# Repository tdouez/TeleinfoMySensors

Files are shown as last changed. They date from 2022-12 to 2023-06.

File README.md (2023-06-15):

# TeleinfoMySensors v2.1.0

Interface Téléinfo pour compteur Linky avec MySensors - version compatible mode standard et historique

Projet utilisant un Arduino Pro micro et un module NRF24L01

- Hardware disponible sur https://www.openhardware.io/view/744/MySensors-Linky
- Boîtier disponible sur https://www.thingiverse.com/thing:3985437
- Description disponible sur http://fumeebleue.fr

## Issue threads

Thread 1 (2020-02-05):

Contact boxenergie

sunsharebox, 2020-02-05:
Bonjour,
Je développe la boxenergie pour les particuliers qui veulent faire des économies d'énergie ou ont du solaire en autoconsommation.(http://demo.sunshare.fr)
Ce projet est opensource sur base raspberry avec liaison filaire sur linky et compteur à impulsion.
Votre solution est intéressante. Je vais la tester sur mon linky.
Je suis en mode standard (115200 BAUD), est ce possible ?
Pourrais on ajouter le traitement des impulsions à votre module radio ?
Il y a plusieurs projets en cours dans la communauté (electronique et informatique) avec l'école polytech de Nantes. Vous pouvez rejoindre notre communauté.
Crdlt.

tdouez, 2020-02-06:
Bonjour,
  Le module est compatible avec le mode  historique en 1200bauds et le nouveau mode en 9600bauds mais la partie logicielle qui a été écrite pour le 1200bauds. Pour le mode impulsionnel il faut aller sur le site de MySensors il y a la description du capteur pour ce mode.

Tristan

Le 6 févr. 2020 à 00:25, sunshare <notifications@github.com> a écrit :

Bonjour,
Je développe la boxenergie pour les particuliers qui veulent faire des économies d'énergie ou ont du solaire en autoconsommation.(http://demo.sunshare.fr)
Ce projet est opensource sur base raspberry avec liaison filaire sur linky et compteur à impulsion.
Votre solution est intéressante. Je vais la tester sur mon linky.
Je suis en mode standard (115200 BAUD), est ce possible ?
Pourrais on ajouter le traitement des impulsions à votre module radio ?
Il y a plusieurs projets en cours dans la communauté (electronique et informatique) avec l'école polytech de Nantes. Vous pouvez rejoindre notre communauté.
Crdlt.

—
You are receiving this because you are subscribed to this thread.
Reply to this email directly, view it on GitHub<https://github.com/tdouez/TeleinfoMySensors/issues/1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>, or unsubscribe<https://github.com/notifications/unsubscribe-auth/ANOTDG5EVMXBZTTPK6JPZ23RBNDHLANCNFSM4KQTYGLQ>.

sunsharebox, 2020-02-06:
Merci, c'est genial.
Ca vous interesse un hackathon en septembre 2020 pendant la nantes digital week ? Je tache d'organiser avec enedis un banc de linky pour des dev open-source.
Julien.
-- envoyé de mon mobile
julien.moreau@sunshare.fr
M:06 51 76 10 42
http://sunshare.fr - Partage d'électricité

Le 6 février 2020 01:59:39 GMT+01:00, "FuméeBleue" <notifications@github.com> a écrit :
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

tdouez, 2020-02-07:
Bonjour,

    C’est une bonne idée mais je ne suis pas de la région et je ne suis pas trop intéressé.
    Pour rappel mon module est open source mais il y a quand même une licence. Il est possible de le modifier, de faire une autre version à la condition de citer la source, moi donc ;).

Tristan

Le 6 févr. 2020 à 08:49, sunshare <notifications@github.com> a écrit :

 Merci, c'est genial.
Ca vous interesse un hackathon en septembre 2020 pendant la nantes digital week ? Je tache d'organiser avec enedis un banc de linky pour des dev open-source.
Julien.
-- envoyé de mon mobile
julien.moreau@sunshare.fr
M:06 51 76 10 42
http://sunshare.fr - Partage d'électricité

Le 6 février 2020 01:59:39 GMT+01:00, "FuméeBleue" <notifications@github.com> a écrit :
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

—
You are receiving this because you commented.
Reply to this email directly, view it on GitHub<https://github.com/tdouez/TeleinfoMySensors/issues/1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>, or unsubscribe<https://github.com/notifications/unsubscribe-auth/ANOTDG52EU4QRMFW2LXWW5TRBO6JZANCNFSM4KQTYGLQ>.

Closed 2022-07-20.

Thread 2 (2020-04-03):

Fabrication PCB

bolosetienne, 2020-04-03:
Bonjour,

J'ai vu que vous n'aviez plus de PCB dans votre boutique, vu la période cela risque d'être compliqué d'en faire fabriquer et de les recevoir rapidement.
Pourriez vous me dire sur quel site vous les faites fabriquer si ca ne vous dérange pas, je souhaiterais le faire mais j'avoue que je n'y connais pas grand chose dans ce domaine, le dernier PCB que j'ai du faire c'était en 1998 au collège!
Quels sont les dimensions et les caractéristique que vous conseillez, et quel fichier faut il envoyer le .brd ou le .sch?

Merci

tdouez, 2020-04-03:
Bonjour,
   Je pense recevoir de nouveaux pcb d’ici une semaine car ils sont arrivés dans les mains de la poste. Un peu de patience.  :)

Tristan

Le 3 avr. 2020 à 20:27, Etienne Laval <notifications@github.com> a écrit :

Bonjour,

J'ai vu que vous n'aviez plus de PCB dans votre boutique, vu la période cela risque d'être compliqué d'en faire fabriquer et de les recevoir rapidement.
Pourriez vous me dire sur quel site vous les faites fabriquer si ca ne vous dérange pas, je souhaiterais le faire mais j'avoue que je n'y connais pas grand chose dans ce domaine, le dernier PCB que j'ai du faire c'était en 1998 au collège!
Quels sont les dimensions et les caractéristique que vous conseillez, et quel fichier faut il envoyer le .brd ou le .sch?

Merci

—
You are receiving this because you are subscribed to this thread.
Reply to this email directly, view it on GitHub<https://github.com/tdouez/TeleinfoMySensors/issues/2>, or unsubscribe<https://github.com/notifications/unsubscribe-auth/ANOTDG3EJTTC5UUXUMQ72ALRKYTAFANCNFSM4L4LKR7Q>.

Closed 2022-07-20.

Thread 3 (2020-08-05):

Soucis de téléversement

Marc--, 2020-08-05:
Salut et merci beaucoup pour ton travail ! Je cherchais exactement ce genre de montage autonome pour mes deux compteurs Linky !

Je viens de terminer la passerelle, pas de soucis, mais j'ai quelques difficultés avec le module TéléInfo. Lors du téléversement, j'ai une erreur:

exit status 1
'read_teleinfo' was not declared in this scope

Je ne comprend pas d'ou ça vient... j'ai suivi ton tuto, je suis en 3.3v, port COM ok, modèle OK... mais rien à faire.

Une idée ?

Bonne soirée !
[Marc]([url](url
[TeleInfoMySensors_errors.txt](https://github.com/tdouez/TeleinfoMySensors/files/5031707/TeleInfoMySensors_errors.txt)
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

))

Marc--, 2020-08-06:
Ok, je suis une tanche. Je pense que l'heure à laquelle j'ai fait ça y est pour quelque chose. J'ai simplement oublié de copier le second .ino dans le dossier du projet.

Merci beaucoup pour ton travail !! Hâte de tester en live.

tdouez, 2020-08-06:
@Marc-- , je suis content pour toi.. :) Merci pour ce retour.

Closed 2020-08-06.

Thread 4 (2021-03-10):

Mode DEBUG

The-MAD-Virus, 2021-03-10:
Bonjour,

Je viens de finir de réaliser mon montage, la communication avec le gateway fonction.
Par contre je n'ai aucune valeur, le Linky est bien en mode standard et si je me connecte directement sur le Linky je vois très bien les tram.
pouvez vous m'aider, le mode debug ne me donne aucune information.

The-MAD-Virus, 2021-03-11:
C'est bon, problème résolu.
La carte Arduino été en 3.3v 8MHz, mais avec un cristal en 16MHz ce qui change la vitesse du Serial.
Après un téléversement en 16MHz tout fonction.

Closed 2021-03-11.

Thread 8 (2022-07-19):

Compatibilité v2.0.0 et "vieux" hardware / Plus de comm après inclusion

Marc--, 2022-07-19:
Bonjour !

J'utilise depuis quelques années ton projet, et ça fonctionnait pas trop mal. Mais quelques erreurs de communication et le fait qu'il y ait une version "2.0" a suffit à me faire mettre à jour.

J'ai donc mis à jour la GW et déployé la version 2.0 sur les modules TIC.  Ils utilisent le PCB daté du 10/2019, avec le NRF24 monté sur un connecteur.

Je n'ai pas de soucis à les inclure dans Jeedom, mais bizarrement une fois inclus, plus aucune communication.

Je doute que le problème soit côté Jeedom, penses tu qu'il puisse y avoir une incompatibilité HW / SW ?? Ca me parait fou car l'inclusion est niquel, le log ne montre plus de caractères inconnus.
Mais on dirait qu'une fois inclu, le module TIC n'a plus rien à dire.

Peux tu me guider sur le debug ?

[mySensors.log](https://github.com/tdouez/TeleinfoMySensors/files/9140216/mySensors.log)
[mySensors_node (1).log](https://github.com/tdouez/TeleinfoMySensors/files/9140217/mySensors_node.1.log)

Marc--, 2022-07-20:
Re,

J'ai flashé une v1.1.5 pour vérifier sans modifier la passerelle et j'ai bien une remontée d'infos régulière.

Je vais essayer de debug un peu en comparant, mais la v2 apporte beaucoup de changement je ne suis pas sur d'aller loin.

Marc--, 2022-07-20:
Je vais me connecter dessus cet aprem. En gros tu veux que je pique la sortie du mosfet BS170 et que je lise sur un terminal pour voir ce qu'il raconte ?

Je suis en mode standard, un compteur "consommation" et l'autre "producteur". J'ai testé sur les deux avec le même résultat.

tdouez, 2022-07-20:
Non il faudrait que tu connectes  sur l'arduino avec le module de programmation FDTI pour lire la sortie série de l'arduino.

Marc--, 2022-07-20:
Bon, c'était instructif. Je note tout au cas ou ça te donne une piste.

Quand je log l'arduino avec le module FTDI, tout semble parfaitement normal. J'ai des updates des valeurs, c'est magique.
Si je le débranche le FTDI, le module continue de fonctionner.

Par contre si je le branche SANS le FTDI, il y a une première communication avec Jeedom, puis plus rien.
La "onboard LED" de l'arduino clignote de manière légère, j'ai comme l'impression qu'il manque de puissance pour démarrer.

Au multimètre j'ai 6v au point de mesure "4".
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

Sur l'arduino, j'ai un 3,3 / 3,2V. Sachant qu'ils sont flashés pour un BOD à 1,8V comme conseillé.

----------------
Autre test

Sur le Linky j'ai connecté uniquement I1 et I2. Pas A. J'alimente donc par le FTDI. Juste après le boot "MySensors 2.3.2", j'ai une suite de caractères blanc. Pas de communication. Je ne peux pas fournir le log car il n'est pas reconnu comme fichier texte.
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

Si je débranche I2 (ou I1), je boot le module (toujours alim FTDI), il démarre puis m'affiche "TIC Mode Standard", et ensuite le boot classique "Fumée Bleue V2.0.0" et ca roule.
[conso-OK.log](https://github.com/tdouez/TeleinfoMySensors/files/9151002/conso-OK.log)

Je décide de supprimer le FTDI. J'alimente le module avec I1 / A, et je laisse I2 débranché. Je lui laisse quelques secondes, je branche I2 : ca marche.

**Ma conclusion: si les bornes I1 et I2 sont connectées au moment du boot du programme, ca plante.**

tdouez, 2022-07-21:
Pour la sortie FDTI, le module commence à mette sa vitesse à 1200 bauds et cherche à recevoir des trames en mode "historique". Si au bout de 10 secondes, les trames ne sont pas reçues il passe en vitesse 9600 bauds qui correspond au mode "standard". Tu es à quelle vitesse sur ton terminal série ? Il faut se mettre à 9600 dans ton cas.
Je pense que dans ton cas l'alimentation du Linky est un peu faible et dans le code le NRF est en mode max (#define MY_RF24_PA_LEVEL     RF24_PA_MAX). Tu peux essayer de passer ne mode HIGH pour avoir une consommation moindre (#define MY_RF24_PA_LEVEL     RF24_PA_HIGH).

Marc--, 2022-07-21:
Je suis bien en 9600 bauds.

Côté puissance, j'ai le même comportement que ce soit alimenté par un moyen externe ou le Linky.

Je suis déja en "RF24_PA_LOW" car j'ai que 5m en champ libre entre la GW et le Linky. J'ai aussi switché "MY_RF24_CHANNEL   1" car c'est le plus loin des mes autres réseaux 2,4Ghz.

Je vais refaire quelques tests, car en V1.1.5 aucun soucis et une fois "bootés" aucun problème non plus. Il n'y a que ce moment au tout début du code (la bascule historique / standard ?) ou ça foire.

Marc--, 2022-07-21:
Alors je précise de suite, je suis pas dev. Je comprend "à peu près".

J'avais dans l'idée que c'était le choix du baud rate qui plantait le programme (les carrés blancs... suspect). Donc sachant que je suis en mode standard, j'ai décidé de ne pas lui laisser le choix. J'ai donc viré la bouche while qui vérifie les trames historiques et forcé le "flag_timeout" à TRUE.

Et ça fonctionne bien. Alors bizarrerie de chez moi ou il y a quelque chose ? Car j'ai le même comportement sur 2 Linky différents (et de marques différentes).

`// ----------------------------------------------------------------
// init_speed_TIC
// ----------------------------------------------------------------
_Mode_e init_speed_TIC()
{
boolean flag_timeout = true;
boolean flag_found_speed = false;
boolean flag_debut_trame = false;
boolean flag_milieu_trame = false;
boolean flag_fin_trame = false;
uint32_t currentTime = millis();
_Mode_e mode;

  digitalWrite(MY_DEFAULT_ERR_LED_PIN, LOW);
  digitalWrite(MY_DEFAULT_RX_LED_PIN, LOW);

  // Test en mode historique
  // Recherche des éléments de début, milieu et fin de trame
  Serial.begin(1200); // mode historique
/*  while (!flag_timeout && !flag_found_speed) {
    if (Serial.available()>0) {
      char in = (char)Serial.read() & 127;  // seulement sur 7 bits
      if (in == 0x0A) flag_debut_trame = true; // début trame
      if (in == 0x20) flag_milieu_trame = true; // milieu trame
      if (in == 0x0D) flag_fin_trame = true; // fin trame

      if (flag_debut_trame && flag_milieu_trame && flag_fin_trame) flag_found_speed = true;
    }
    if (currentTime + 10000 <  millis()) flag_timeout = true; // 10s de timeout
  }
*/
  if (flag_timeout) { // trame avec vistesse histo non trouvée donc passage en mode standard
     mode = TINFO_MODE_STANDARD;
     Serial.end();
     Serial.begin(9600); // mode standard
     Serial.println(F("TIC mode standard"));
     clignote_led(MY_DEFAULT_RX_LED_PIN, 3, 500);
  }
  else {
    mode = TINFO_MODE_HISTORIQUE;
    Serial.println(F("TIC mode historique"));
    clignote_led(MY_DEFAULT_RX_LED_PIN, 5, 500);
  }

  digitalWrite(MY_DEFAULT_ERR_LED_PIN, HIGH);

  return mode;
}

`

tdouez, 2022-07-22:
ok merci pour ce test. Je vais vérifier cela de mon côté avec un compteur en mode standard.

tdouez, 2022-07-22:
Après quelques recherches, le problème est peut-être lié à la tentative de lecture du serial en 1200 bauds et ensuite le passage en 9600 bauds. Il y aurait une augmentation de la consommation de l'arduino dans ce cas; ce qui peut poser problème avec le module.
Je ferai un test dès que j'ai accès à un compteur en mode standard (je suis en histo chez moi) .

tdouez, 2022-09-27:
C'est bon le problème est normalement résolu avec la version v2.0.1

Closed 2022-09-27.

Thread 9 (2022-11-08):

Valeur fluctuante

The-MAD-Virus, 2022-11-08:
Bonjour,

Tout d'abord merci, cela fait déjà un an que j'utilise ton projet avec Home-Assistant.
Tout marche à merveille, mais ressemant Home-Assistant ajouter une interface pour visualiser la consommation/production de son logement et c'est la que je me suis rendu compte qu'il y avait un problème avec les valeurs retourner.
EASF01 et EASF02 retournent par moment zéro ou la valeur actuelle plus un nombre aléatoire ( ex: 54586 + 528 = 54586528).
Je n'arrive pas à savoir si cela vient du code ou du circuit imprimé.

Pour les valeurs à zéro je vois bien comment corriger le code, mais pour l'autre type d'erreur je n’ai aucune idée.

Voilà je suis preneur de toute piste pour corriger ces erreurs.

brag00n, 2023-02-01:
Bonjour,

Je constate la même chose sur Jeedom
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

tdouez, 2023-02-01:
Hello, ok je vais analyser mon code. Vous utilisez quelle version ?

The-MAD-Virus, 2023-02-02:
Bonjour,

J'utilise la version 2.0.1, malheureusement je n'ai pas d'oscilloscope sous la main pour contrôler mon circuit.
Je me demande si il n’y a pas un problème au niveau du découpage des trames.

tdouez, 2023-02-02:
Bonjour @The-MAD-Virus  et @brag00n ,
    Pour le récupération des etiquettes TIC dont la série EASF.., j'utilise la librairie libTeleinfo que j'ai légèrement modifiée pour gagner de la place mémoire.  J'ai récupéré la dernière version de cette librairie avec un correctif notamment sur des problèmes d'interruptions de trame qui peut engendrer des valeurs incohérentes.
    Je vais donc mettre en ligne ce correctif avec la version 2.0.3.

     Je garde l'incident ouvert. Avez-vous la possibilité de récupérer cette dernière version et me faire un retour ?

The-MAD-Virus, 2023-02-02:
Super, je test ça ce soir.

The-MAD-Virus, 2023-02-03:
Salut,
J'ai fait la mise ajour, mais n'a rien changer pour moi.

exemple de valeur pour la variable LTARF :

- HEURE PLEINE
- HEURE PLEINE77769
- HEURE PLEINE
- HEURE PLEINE77726
- HEURE PLEINE
- 677525

tdouez, 2023-02-09:
@The-MAD-Virus , merci pour ce retour. Je ne vois pas de problématique dans le code avec une lecture approfondie. Je vais passer à l'étape sonde de bas niveau afin de voir si le problème vient de l'entrée TIC hardware ou logiciel, la partie librairie Teleinfo ou côté MySensors.

The-MAD-Virus, 2023-02-09:
De mon coté je vais remplacer les cables entre le Linky et circuit imprimer, on ne sais jamais si ce n'est pas des signaux parasite qui interfère.
Après au niveau de la librairie le checksum se fait avec la date il me semble, peut être un problème de synchro ?

tdouez, 2023-02-13:
@The-MAD-Virus et/ou @brag00n, vous tous les deux sous HA ? avez-vous la log brutes sortant de la gateway MySensors ? Est-ce que ces valeurs erronées sont déjà présentes ? Sur le code du module, il y a une vérif de checksum juste avant l'envoi des données MySensors donc les données sont correctes sans altération par des parasites.

The-MAD-Virus, 2023-02-13:
J'ai fait le test ce week-end avec une liaison "_EMF Free_" entre Linky et le circuit, mais ça n'a rien changé.
Et pour répondre a ta question oui, j'utilise HA, il me semble que j'avais déjà regardé les log et les informations été identique.
Je vais quand même repasser HA en mode débug pour vérifié.

tdouez, 2023-02-13:
@The-MAD-Virus, j'utilise actuelle le module RFM chez moi. Je remettre en ligne le module MySesnors et le surveiller de près (avec sonde) mais je suis personnellement en TIC standard et non historique mais le problème devrait aussi apparaître.
Question : as-tu la possibilité de mettre une sonde usb fdti sur l'arduino du module Linky ? Si oui, j'aurais besoin de ton aide ;)

The-MAD-Virus, 2023-02-13:
Valeur erroné:
```
2023-02-13 16:36:53.346 DEBUG (MainThread) [mysensors.transport] Receiving 3;4;1;0;47;H PLE91657
2023-02-13 16:36:53.349 DEBUG (MainThread) [homeassistant.components.mysensors.gateway] Node update: node 3 child 4
2023-02-13 16:36:53.366 DEBUG (MainThread) [homeassistant.components.mysensors.device] Entity update: NJOURF+1: value_type 47, value = 00
2023-02-13 16:36:53.367 DEBUG (MainThread) [homeassistant.components.mysensors.device] Entity update: NJOURF+1: value_type 47, value = 00
2023-02-13 16:36:53.439 DEBUG (MainThread) [mysensors.transport] Receiving 3;7;1;0;18;6599145
2023-02-13 16:36:53.440 DEBUG (MainThread) [homeassistant.components.mysensors.gateway] Node update: node 3 child 7
2023-02-13 16:36:53.455 DEBUG (MainThread) [homeassistant.components.mysensors.device] Entity update: NGTF: value_type 47, value = H PLE91657
2023-02-13 16:36:53.455 DEBUG (MainThread) [homeassistant.components.mysensors.device] Entity update: NGTF: value_type 43, value = Wh
2023-02-13 16:36:53.455 DEBUG (MainThread) [homeassistant.components.mysensors.device] Entity update: NGTF: value_type 47, value = H PLE91657
2023-02-13 16:36:53.455 DEBUG (MainThread) [homeassistant.components.mysensors.device] Entity update: NGTF: value_type 43, value = Wh
```

Valeur correct:
```
2023-02-13 16:36:55.561 DEBUG (MainThread) [mysensors.transport] Receiving 3;5;1;0;47; HEURE  PLEINE
2023-02-13 16:36:55.562 DEBUG (MainThread) [homeassistant.components.mysensors.gateway] Node update: node 3 child 5
2023-02-13 16:36:55.568 DEBUG (MainThread) [homeassistant.components.mysensors.device] Entity update: NGTF: value_type 47, value = H PLEINE/CREUSE
2023-02-13 16:36:55.569 DEBUG (MainThread) [homeassistant.components.mysensors.device] Entity update: NGTF: value_type 43, value = Wh
2023-02-13 16:36:55.569 DEBUG (MainThread) [homeassistant.components.mysensors.device] Entity update: NGTF: value_type 47, value = H PLEINE/CREUSE
2023-02-13 16:36:55.569 DEBUG (MainThread) [homeassistant.components.mysensors.device] Entity update: NGTF: value_type 43, value = Wh
```

tdouez, 2023-02-13:
Ok mais c'est des données déjà interprétée par HA. Au niveau de l'interface Mysensors, tu n'as pas la possibilité d'avoir les trames brutes Mysensors ?

The-MAD-Virus, 2023-02-14:
> Question : as-tu la possibilité de mettre une sonde usb fdti sur l'arduino du module Linky ? Si oui, j'aurais besoin de ton aide ;)

OK, ce soir je branche le fdti et je tente d'enregistrer les logs.
As tu une idée de ce que tu cherche ? (le fichier risque d’être long).

tdouez, 2023-02-14:
J’ai installé un HA sur mon pc et il est possible d’activer le journal de debug sur le Mysensors au niveau des appareils et services. Ensuite tu trouveras les trames brutes dans le journal de HA. Il est possible de le télécharger complètement.

Le 14 févr. 2023 à 12:35, The-MAD-Virus ***@***.***> a écrit :

Question : as-tu la possibilité de mettre une sonde usb fdti sur l'arduino du module Linky ? Si oui, j'aurais besoin de ton aide ;)

OK, ce soir je branche le fdti et je tente d'enregistrer les logs.
As tu une idée de ce que tu cherche ? (le fichier risque d’être long).
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
tdouez, 2023-02-14:
ok, ça marche. Reste à savoir si le problème est à la lecture la l'interface série. Pour cela, il faut ajouter un print lors de la lecture de l'entrée Serial; ce n'est pas dans le code actuellement.  Dans le fichier libTeleinfoLite.cpp, peut-tu ajouter la ligne suivant "Serial.print(c);"  juste avant la ligne "switch (c) {". Et ensuite reflasher le firmeware et mettre le connecteur FDTI pour récupérer la sortie Serial. Oui, c'est verbeux mais je ne vois pas comment faire autrement. De mon côté, je fais le test avec mon HA nouvellement installé.. bon je découvre et j'ai un peu de mal pour récupérer l'ensemble de mes étiquettes/entités...

The-MAD-Virus, 2023-02-15:
Je n'ai pas pu logger plus long temps, je ne sais pas si cela suffira, mais voici le [lien](https://drive.google.com/file/d/1rdqIj8HZJYt0WQIQNJr_1tWqYOQUY0Pb/view?usp=share_link) du fichier.

ps: Je ne pourrai plus faire de tests dans les prochains jours, je pars en congé.

tdouez, 2023-02-15:
Merci.
    Dans ce lot je n’ai pas vu de problème. En fait il faudrait avoir son pendant avec la log HA. Trouver le pb côté HA et voir si il existe côté arduino.

Le 15 févr. 2023 à 09:57, The-MAD-Virus ***@***.***> a écrit :

Je n'ai pas pu logger plus long temps, je ne sais pas si cela suffira, mais voici le lien<https://emea01.safelinks.protection.outlook.com/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> du fichier.

ps: Je ne pourrai plus faire de tests dans les prochains jours, je pars en congé.

—
Reply to this email directly, view it on GitHub<https://emea01.safelinks.protection.outlook.com/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>, or unsubscribe<https://emea01.safelinks.protection.outlook.com/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>.
You are receiving this because you modified the open/close state.Message ID: ***@***.***>

The-MAD-Virus, 2023-03-13:
J'ai refait des tests, mais bien sur pas de gros bug juste quel que valeur a zéro.
Je copie quand même un exemple où une valeur à zéro est envoyé.

Log HA :
```sql
2023-03-12 18:30:47.284 DEBUG (MainThread) [mysensors.transport] Receiving 3;53;1;0;38;0
2023-03-12 18:30:47.285 DEBUG (MainThread) [homeassistant.components.mysensors.gateway] Node update: node 3 child 53
2023-03-12 18:30:47.386 DEBUG (MainThread) [homeassistant.components.mysensors.device] Entity update: UMOY1: value_type 38, value = 0
2023-03-12 18:30:47.386 DEBUG (MainThread) [homeassistant.components.mysensors.device] Entity update: UMOY1: value_type 43, value = V
```

Log ftdi :
```sql
18:30:47:817 -> PCOUP	06	_3516359 TSF:MSG:SEND,3-3-0-0,s=33,c=1,t=55,pt=4,l=4,sg=0,ft=0,st=OK:6
18:30:47:896 ->
18:30:47:896 -> SINSTS	01426	3305	07138	V
18:30:47:928 -> UMOY1	H2303E         		00	&
18:30:47:960 -> NJOUR6C001 NONUTILE NONUTILE NONUTILE NONUTILE NONUTILE NONUTILE NONUTILE NONUTILE	\
18:30:48:045 -> ADSC	041964289873	J3516589 TSF:MSG:SEND,3-3-0-0,s=1,c=1,t=47,pt=0,l=12,sg=0,ft=0,st=OK:041964289873
```

tdouez, 2023-03-14:
de mon côté, j'ai installé HA mais je n'arrive pas à récupérer les étiquettes, je ne vous qu'une seule valeur "base". L"intégration mysensors Linky sous HA se réalise comment ? En modifiant le config yaml ?

The-MAD-Virus, 2023-03-17:
Normalement si le Gateway est bien configurer les Nodes se mette a jour tout seul.
Quelle type de Gateway utilise tu ? (Sérial, Ethernet, MQTT)
Après il ce peut que, si tu as fait plusieurs test que le fichier qui sauvegarde les Nodes soit corrompu (MySensors#######.json).
Sa met déjà arriver, je l'ai simplement supprimer et redémarrer Home-Assitante pour repartir de zéro.

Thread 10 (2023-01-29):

Envois trames à la Gateway

secator76, 2023-01-29:
Bonjour Tristan,

tu initialises 2 variables :

const unsigned long SEND_FREQUENCY_FULL = 180000; // 3mn, Minimum time between send (in milliseconds).
const unsigned long SEND_FREQUENCY_TIC  =  15000; // 15s,  Minimum time between send (in milliseconds).

qui permettent d'envoyer les trames à la gateway toutes les 3 minutes ou toutes les 15 secondes or ces variables sont ensuite utilisées nulle part dans le programme ce qui fait que la gateway est bombardées de trames et par voie de conséquence mon domoticz aussi. Comment faire pour utiliser ces variables.

Ensuite que faut il modifier pour envoyer EAST,EASF01,EASF02...EASF10 en Kwh (avec 3 chifffres après la virgule) et non pas en wh car domoticz créé un capteur qui attends des Kwh.

Merci.

tdouez, 2023-01-30:
Bonjour,
    Pour cela tu es obligé de changer la valeur des constantes, recompiler le code et flasher l’arduino. Le code actuel ne permet pas de mettre à jour ces valeurs via un envoi gateway vers le module Linky. Je peux mettre cela dans ma « todo list » ;)

    La même chose pour les champs en watt/heure, je peux prévoir une commande de pour les passer en kwh. En attendant, il faut modifier le code lors des commandes « send(…. ».

Tristan

Le 29 janv. 2023 à 09:57, secator76 ***@***.***> a écrit :

Bonjour Tristan,

tu initialises 2 variables :

const unsigned long SEND_FREQUENCY_FULL = 180000; // 3mn, Minimum time between send (in milliseconds).
const unsigned long SEND_FREQUENCY_TIC = 15000; // 15s, Minimum time between send (in milliseconds).

qui permettent d'envoyer les trames à la gateway toutes les 3 minutes ou toutes les 15 secondes or ces variables sont ensuite utilisées nulle part dans le programme ce qui fait que la gateway est bombardées de trames et par voie de conséquence mon domoticz aussi. Comment faire pour utiliser ces variables.

Ensuite que faut il modifier pour envoyer EAST,EASF01,EASF02...EASF10 en Kwh (avec 3 chifffres après la virgule) et non pas en wh car domoticz créé un capteur qui attends des Kwh.

Merci.

—
Reply to this email directly, view it on GitHub<https://emea01.safelinks.protection.outlook.com/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>, or unsubscribe<https://emea01.safelinks.protection.outlook.com/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>.
You are receiving this because you are subscribed to this thread.Message ID: ***@***.***>

secator76, 2023-01-30:
Bonsoir,

merci pour ta réponse mais je ne suis pas assez calé pour faire ces modifications.sur ta dernière version. En attendant une eventuelle prise en compte dans tes prochaines versions, je vais me rabattre sur la 1.1.6 qui est plus de mon niveau.
En tout cas merci pour ton travail. ça fonctionne très bien.

Bonne soirée.

secator76, 2023-02-02:
ok, merci. Une possibilité d'envoyer en kWh et non en Wh et c'est parfait.

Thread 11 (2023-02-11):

Pas de remontée dans HA

ayu69, 2023-02-11:
Bonjour,

J'ai réceptionné le module cette semaine, je l'ai programmé, puis raccorder jusque la pas de souci, ma passerelle voit bien le module.

En revanche sur Homeassistant je n'ai que ça :

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

et je n'arrive pas à comprendre comment récupérer les différentes infos

Merci d'avance

tdouez, 2023-02-11:
Bonjour,
   Je ne connais pas bien Hope assistant étant sous Jeedom. Je suppose que tu passe par un module Mysensors sur le HA, il devrait avoir la possibilité de voir les logs afin de vérifier les donnés brutes.
   Au démarrage le module Linky passe par l’étape de présentation pour lister l’ensemble des étiquettes qui seront alimentées ensuite. Tu devrais avoir cela dans les logs.

   Tristan

Le 11 févr. 2023 à 13:21, Quentin Marques ***@***.***> a écrit :

Bonjour,

J'ai réceptionné le module cette semaine, je l'ai programmé, puis raccorder jusque la pas de souci, ma passerelle voit bien le module.

En revanche sur Homeassistant je n'ai que ça :

[image]<https://emea01.safelinks.protection.outlook.com/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>

et je n'arrive pas à comprendre comment récupérer les différentes infos

Merci d'avance

—
Reply to this email directly, view it on GitHub<https://emea01.safelinks.protection.outlook.com/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>, or unsubscribe<https://emea01.safelinks.protection.outlook.com/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>.
You are receiving this because you are subscribed to this thread.Message ID: ***@***.***>

ayu69, 2023-02-11:
Bonjour,

Autant le module se présente effectivement bien à ma paserelle, voila ce que j'ai dans le json :

`    "10": {
        "sensor_id": 10,
        "children": {
            "1": {
                "id": 1,
                "type": 36,
                "description": "ADSC",
                "values": {}
            },
            "2": {
                "id": 2,
                "type": 36,
                "description": "VTIC",
                "values": {}
            },
            "3": {
                "id": 3,
                "type": 36,
                "description": "DATE",
                "values": {}
            },
            "4": {
                "id": 4,
                "type": 36,
                "description": "NGTF",
                "values": {}
            },
            "5": {
                "id": 5,
                "type": 36,
                "description": "LTARF",
                "values": {}
            },
            "6": {
                "id": 6,
                "type": 13,
                "description": "EAST",
                "values": {}
            },
            "7": {
                "id": 7,
                "type": 13,
                "description": "EASF01",
                "values": {}
            },
            "8": {
                "id": 8,
                "type": 13,
                "description": "EASF02",
                "values": {}
            },
            "9": {
                "id": 9,
                "type": 13,
                "description": "EASF03",
                "values": {}
            },
            "10": {
                "id": 10,
                "type": 13,
                "description": "EASF04",
                "values": {}
            },
            "11": {
                "id": 11,
                "type": 13,
                "description": "EASF05",
                "values": {}
            },
            "12": {
                "id": 12,
                "type": 13,
                "description": "EASF06",
                "values": {}
            },
            "13": {
                "id": 13,
                "type": 13,
                "description": "EASF07",
                "values": {}
            },
            "14": {
                "id": 14,
                "type": 13,
                "description": "EASF08",
                "values": {}
            },
            "15": {
                "id": 15,
                "type": 13,
                "description": "EASF09",
                "values": {}
            },
            "16": {
                "id": 16,
                "type": 13,
                "description": "EASF10",
                "values": {}
            },
            "17": {
                "id": 17,
                "type": 13,
                "description": "EASD01",
                "values": {}
            },
            "18": {
                "id": 18,
                "type": 13,
                "description": "EASD02",
                "values": {}
            },
            "19": {
                "id": 19,
                "type": 13,
                "description": "EASD03",
                "values": {}
            },
            "20": {
                "id": 20,
                "type": 13,
                "description": "EASD04",
                "values": {}
            },
            "21": {
                "id": 21,
                "type": 13,
                "description": "EAIT",
                "values": {}
            },
            "22": {
                "id": 22,
                "type": 13,
                "description": "ERQ1",
                "values": {}
            },
            "23": {
                "id": 23,
                "type": 13,
                "description": "ERQ2",
                "values": {}
            },
            "24": {
                "id": 24,
                "type": 13,
                "description": "ERQ3",
                "values": {}
            },
            "25": {
                "id": 25,
                "type": 13,
                "description": "ERQ4",
                "values": {}
            },
            "26": {
                "id": 26,
                "type": 30,
                "description": "IRMS1",
                "values": {}
            },
            "27": {
                "id": 27,
                "type": 30,
                "description": "IRMS2",
                "values": {}
            },
            "28": {
                "id": 28,
                "type": 30,
                "description": "IRMS3",
                "values": {}
            },
            "29": {
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
ayu69, 2023-02-18:
Oui j'ai assez rapidement fixé l'ID avec les microswitch, dans le doute que cela puisse venir de la mais visiblement rien

Tu pense vraiment à un souci hardware ?

tdouez, 2023-02-18:
Peux tu me faire une photo du circuit d’alimentation? Il y a un mosfet juste à droite de l’optocoupleur. A voir si il y a pas un souci de soudure.

Le 18 févr. 2023 à 17:42, Quentin Marques ***@***.***> a écrit :

Oui j'ai assez rapidement fixé l'ID avec les microswitch, dans le doute que cela puisse venir de la mais visiblement rien

Tu pense vraiment à un souci hardware ?

—
Reply to this email directly, view it on GitHub<https://emea01.safelinks.protection.outlook.com/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>, or unsubscribe<https://emea01.safelinks.protection.outlook.com/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>.
You are receiving this because you commented.Message ID: ***@***.***>

ayu69, 2023-02-19:
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

Difficile de voir bien

tdouez, 2023-02-19:
Oui c'est assez difficile. Je viens de t'envoyer un autre module qui est 100% fonctionnel. Peux tu l'utiliser et me faire un retour. Il faudra me renvoyer celui qui est hs.

ayu69, 2023-02-19:
Aucun souci,
Je te fait un retour dès que possible.

Merci pour ta réactivité.

ayu69, 2023-02-25:
Bonjour,

Rien à faire j'ai toujours le même souci, du coup on peut exclure le côté matériel.
Je à part le code je ne vois pas vraiment.

Du point de vue de HA j'ai quand même du "mieux" :
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

J'ai maintenant la possibilités d'envoyer des commandes au modules, et lorsque je le fait, la led orange du module linky clignote 1 fois.

Donc la communication se fait bel et bien.

En revanche à part la présentation, aucune valeurs ne s'affiche dans le fichier json....

tdouez, 2023-02-26:
Hello,
    Bon ça avance, pas de souci côté matériel. J’ai essayé chez moi le home assistant et j’ai aussi la visu que de la premier étiquette BASE. Je n’arrive pas à avoir les autres, je vais continuer à chercher. Côté code pas de souci car cela fonctionne très bien avec Jeedom.

Tristan

Le 25 févr. 2023 à 12:37, Quentin Marques ***@***.***> a écrit :

Bonjour,

Rien à faire j'ai toujours le même souci, du coup on peut exclure le côté matériel.
Je à part le code je ne vois pas vraiment.

Du point de vue de HA j'ai quand même du "mieux" :
[image]<https://emea01.safelinks.protection.outlook.com/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>

J'ai maintenant la possibilités d'envoyer des commandes au modules, et lorsque je le fait, la led orange du module linky clignote 1 fois.

Donc la communication se fait bel et bien.

En revanche à part la présentation, aucune valeurs ne s'affiche dans le fichier json....

—
Reply to this email directly, view it on GitHub<https://emea01.safelinks.protection.outlook.com/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>, or unsubscribe<https://emea01.safelinks.protection.outlook.com/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>.
You are receiving this because you commented.Message ID: ***@***.***>

Closed 2023-06-01.

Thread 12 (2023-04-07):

spam de la gateway

ssdrun, 2023-04-07:
Bonjour,

Je vous écris car suite à la mise à jour du firmware vers la v2.0.5, les données sont transmises en permanence, sans délai et/ou sans tenir compte de la mise à jour ou non des données du linky. Cela spam la gateway et j'ai des données erronées très fréquentes qui apparaissent en Home Assistant. pourriez vous m'aider à comprendre la raison s'il vous plait ? bug du firmware ou problème de mon coté ?
Ci-joint un extrait des logs de reception de la gateway depuis HA et une capture d'écran des erreurs (toutes ne sont pas visibles)
Merci,

Samuel

[HA-mysensors-gateway-log.txt](https://github.com/tdouez/TeleinfoMySensors/files/11181175/HA-mysensors-gateway-log.txt)
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

tdouez, 2023-04-07:
Bonjour,
  Ok je vais regarder.
Tristan

Le 7 avr. 2023 à 22:05, ssdrun ***@***.***> a écrit :

Bonjour,

Je vous écris car suite à la mise à jour du firmware vers la v2.0.5, les données sont transmises en permanence, sans délai et/ou sans tenir compte de la mise à jour ou non des données du linky. Cela spam la gateway et j'ai des données erronées très fréquentes qui apparaissent en Home Assistant. pourriez vous m'aider à comprendre la raison s'il vous plait ? bug du firmware ou problème de mon coté ?
Ci-joint un extrait des logs de reception de la gateway depuis HA et une capture d'écran des erreurs (toutes ne sont pas visibles)
Merci,

Samuel

HA-mysensors-gateway-log.txt<https://github.com/tdouez/TeleinfoMySensors/files/11181175/HA-mysensors-gateway-log.txt>
[erreur données HA]<https://user-images.githubusercontent.com/120454521/230671592-f25fe067-a72b-46e7-9e61-5671d6ea9a86.png>

—
Reply to this email directly, view it on GitHub<https://github.com/tdouez/TeleinfoMySensors/issues/12>, or unsubscribe<https://github.com/notifications/unsubscribe-auth/ANOTDG6AOKHCQGUT25RBX5LXABXO3ANCNFSM6AAAAAAWW4F7YM>.
You are receiving this because you are subscribed to this thread.Message ID: ***@***.***>

tdouez, 2023-04-11:
Tu étais sur quelle version auparavant, la v2.0.4 ? Pour savoir si ce problème est lié à la dernière mise à jour ou suite au changement de librairie libTeleinfo. L'envoi des données via Mysensors est lié au rafraichissement des étiquettes lues par la librairie libTeleinfo; il n'y a pas de réglage actuellement sur la fréquence des send sous Mysensors.
Pour les infos erronées, je n'ai pas encore trouvé la raison, car il y a bien une vérification du checksum avant l'envoi des données.

tdouez, 2023-04-11:
ok, je comprends mieux. Je vais faire une petite évolution de mon code pour gérer cette problématique.

tdouez, 2023-04-11:
Peux-tu réaliser un test avec cette modification ? J'ai ajouté un délai d'une seconde entre les émissions vers la gateway.
[TeleinfoMySensors.ino.zip](https://github.com/tdouez/TeleinfoMySensors/files/11202654/TeleinfoMySensors.ino.zip)

ssdrun, 2023-04-11:
ok , je teste et te reviens vers toi,
Merci

ssdrun, 2023-04-11:
Alors ça semble beaucoup mieux, mais on pourrait gagner en fluidité si on pouvait empecher l'envoi de données non modifiées.
Car sont toujours envoyée à priori toutes les données dont celle qui ne changent jamais : OPTARIF, ISOUSC, PTEC, HHPHC, IMAX, MOTDETAT, ADCO,
Je te joins le log.
Merci !
Samuel
[HA-mysensors-gateway-log_V2.0.6.txt](https://github.com/tdouez/TeleinfoMySensors/files/11202825/HA-mysensors-gateway-log_V2.0.6.txt)

ssdrun, 2023-04-11:
mais si cela est trop complexe à gérer, il me suffit peut-etre de commenter les lignes de code qui envoient ces données inutiles...

ssdrun, 2023-04-12:
Salut,

Alors après une nuit de fonctionnement, les logs montrent encore quelques erreurs. Et cette fois j'ai désactivé quasiment tous mes autres sensors afin de n'avoir que des logs de la carte linky FB. Les erreurs semblent donc venir de la carte... puisque la gateway n'est plus spamée... En fait la seule erreur est sur la donnée BASE: qui par moment est erronée (ci-dessous 4 valeurs proches de 0 trouvées dans les logs).

`2023-04-11 23:15:22.965 DEBUG (MainThread) [homeassistant.components.mysensors.device] Entity update: BASE: value_type 18, value = 0

2023-04-12 00:42:20.842 DEBUG (MainThread) [homeassistant.components.mysensors.device] Entity update: BASE: value_type 18, value = 0

2023-04-12 04:36:27.086 DEBUG (MainThread) [homeassistant.components.mysensors.device] Entity update: BASE: value_type 18, value = 0

2023-04-12 06:22:16.414 DEBUG (MainThread) [homeassistant.components.mysensors.device] Entity update: BASE: value_type 18, value = 580`

Sachant que cette valeur est incrémentielle, ne serait-il pas possible de vérifier que la valeur soit supérieure ou égale à la précédente avant envoi ? avec aussi une sécurité sur la valeur haute au cas où ? (genre  Valeur BASE précédente <= BASE actuelle < BASE +  1000)

Je te joins les logs.
Merci

Samuel
[HA-mysensors-gateway-log_V2.0.6_night.txt](https://github.com/tdouez/TeleinfoMySensors/files/11207025/HA-mysensors-gateway-log_V2.0.6_night.txt)
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

ssdrun, 2023-04-14:
Alors, ça a fonctionné impeccable toute la nuit et aujourd'hui jusqu'à ce message recu par la gateway (en gras):

2023-04-14 15:32:34.802 DEBUG (MainThread) [mysensors.transport] Receiving 27;4;1;0;18;21180817
**2023-04-14 15:33:04.585 DEBUG (MainThread) [mysensors.transport] Receiving 27;4;1;0;18;1094922648**
2023-04-14 15:33:04.657 DEBUG (MainThread) [mysensors.transport] Receiving 27;4;1;0;18;21180824

qui est hors norme part rapport aux valeurs précédentes et suivantes reçues :
Soit le programme ne fonctionne pas correctement.. mais il me semble bien écrit pour écarter ce type de valeur transmise...donc j'en doute...
Soit j'ai un problème avec la gateway qui "entend" n'importe quoi ... je vais tenter d'isoler le module.. peut-etre est-il trop parasité...

Je tente une amélioration matérielle et retesterai ce week-end...

tdouez, 2023-04-14:
En effet, le code modifié évite se genre de désagrément. Je vais quand même vérifier mon code.

Le 14 avr. 2023 à 14:44, ssdrun ***@***.***> a écrit :

Alors, ça a fonctionné impeccable toute la nuit et aujourd'hui jusqu'à ce message recu par la gateway (en gras):

2023-04-14 15:32:34.802 DEBUG (MainThread) [mysensors.transport] Receiving 27;4;1;0;18;21180817
2023-04-14 15:33:04.585 DEBUG (MainThread) [mysensors.transport] Receiving 27;4;1;0;18;1094922648
2023-04-14 15:33:04.657 DEBUG (MainThread) [mysensors.transport] Receiving 27;4;1;0;18;21180824

qui est hors norme part rapport aux valeurs précédentes et suivantes reçues :
Soit le programme ne fonctionne pas correctement.. mais il me semble bien écrit pour écarter ce type de valeur transmise...donc j'en doute...
Soit j'ai un problème avec la gateway qui "entend" n'importe quoi ... je vais tenter d'isoler le module.. peut-etre est-il trop parasité...

Je tente une amélioration matérielle et retesterai ce week-end...

—
Reply to this email directly, view it on GitHub<https://github.com/tdouez/TeleinfoMySensors/issues/12#issuecomment-1508451402>, or unsubscribe<https://github.com/notifications/unsubscribe-auth/ANOTDG3WQAFUG6XTZ5NO2Z3XBFBEPANCNFSM6AAAAAAWW4F7YM>.
You are receiving this because you commented.Message ID: ***@***.***>

tdouez, 2023-06-01:
A priori c'est bon. Pas de retour.

Closed 2023-06-01.

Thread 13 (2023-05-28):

Actualisation index de conso

davidmarli, 2023-05-28:
Bonjour,

sur la version 2.0.7, l'actualisation des index se fait de façon peu fréquente et seulement toutes les 2 minutes environ

Sun May 28 2023 06:00:33 GMT+0100 (British Summer Time) : 1;8;1;0;18;11633490
Sun May 28 2023 06:00:33 GMT+0100 (British Summer Time) : 1;8;1;0;18;11633490
Sun May 28 2023 06:01:45 GMT+0100 (British Summer Time) : 1;8;1;0;18;11633498
Sun May 28 2023 06:01:45 GMT+0100 (British Summer Time) : 1;8;1;0;18;11633498
Sun May 28 2023 06:02:51 GMT+0100 (British Summer Time) : 1;8;1;0;18;11633506
Sun May 28 2023 06:02:51 GMT+0100 (British Summer Time) : 1;8;1;0;18;11633506
Sun May 28 2023 06:04:06 GMT+0100 (British Summer Time) : 1;8;1;0;18;11633514
Sun May 28 2023 06:04:06 GMT+0100 (British Summer Time) : 1;8;1;0;18;11633514

tdouez, 2023-06-01:
Je ne vois de souci dans le code mais son fonctionnement n'est pas parfait car il va lire toutes les secondes l'entrée tic serial et ensuite transmettre de suite l'info vers la gateway. Pendant ce laps de temps il n'y a pas de lecture de l'entrée tic; il est possible de louper de l'information..
J'essaye de revoir mon code en mémorisant les étiquettes/valeurs tic mais cela demande trop de RAM vis à vis du petit arduino 328, surtout dans le mode standard (71 étiquettes à mémoriser).

tdouez, 2023-06-15:
le problème doit être corrigé sur la version 2.1.0 mais demande l'utilisation d'un arduino pro micro afin d'avoir un peu plus de mémoire RAM.

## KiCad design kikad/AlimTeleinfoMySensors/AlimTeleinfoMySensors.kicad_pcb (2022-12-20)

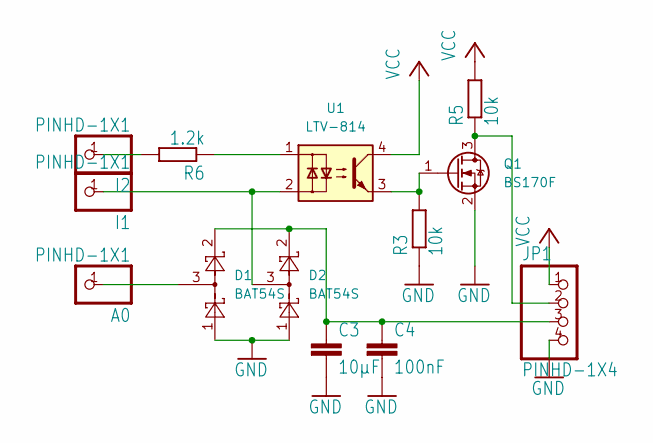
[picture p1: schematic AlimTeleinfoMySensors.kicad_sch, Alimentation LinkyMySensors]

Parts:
A0: PINHD-1X1; 1X01
C3: 10µF; C_1210_3225Metric
C4: 100nF; C_1206_3216Metric
D1, D2: BAT54S; SOT-23
I1, I2: PINHD-1X1; 1X01
JP1: PINHD-1X4; 1X04
Q1: BS170F; SOT-23
R3, R5: 10k; R_1206_3216Metric
R6: 1.2k; R_1206_3216Metric
U1: LTV-814; DIP-4_W7.62mm

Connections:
GND: C3.2, C4.2, D1.1, D2.1, JP1.4, Q1.2 (S), R3.1
unnamed: A0.1, D1.3
unnamed: C3.1, C4.1, D1.2, D2.2, JP1.3
unnamed: D2.3, I1.1, U1.2
unnamed: I2.1, R6.2
unnamed: JP1.2, Q1.3 (D), R5.1
unnamed: Q1.1 (G), R3.2, U1.3
unnamed: R6.1, U1.1
VCC: JP1.1, R5.2, U1.4

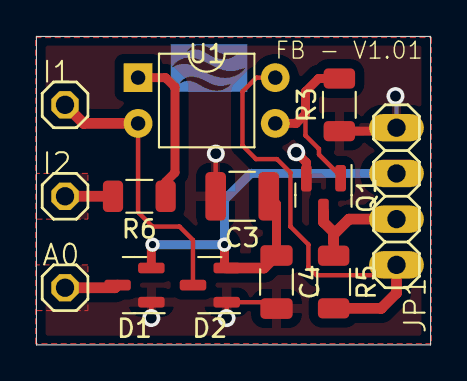
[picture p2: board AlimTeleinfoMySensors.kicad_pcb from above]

Board: 2 copper layers, 21.9 x 17.1 mm, 14 parts (0 on the bottom side), 9 nets.

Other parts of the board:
U$1: FB

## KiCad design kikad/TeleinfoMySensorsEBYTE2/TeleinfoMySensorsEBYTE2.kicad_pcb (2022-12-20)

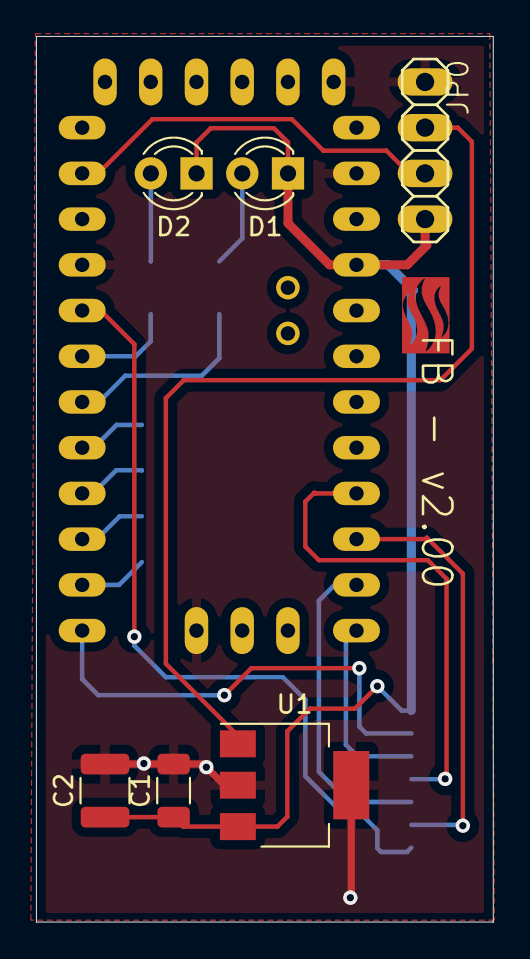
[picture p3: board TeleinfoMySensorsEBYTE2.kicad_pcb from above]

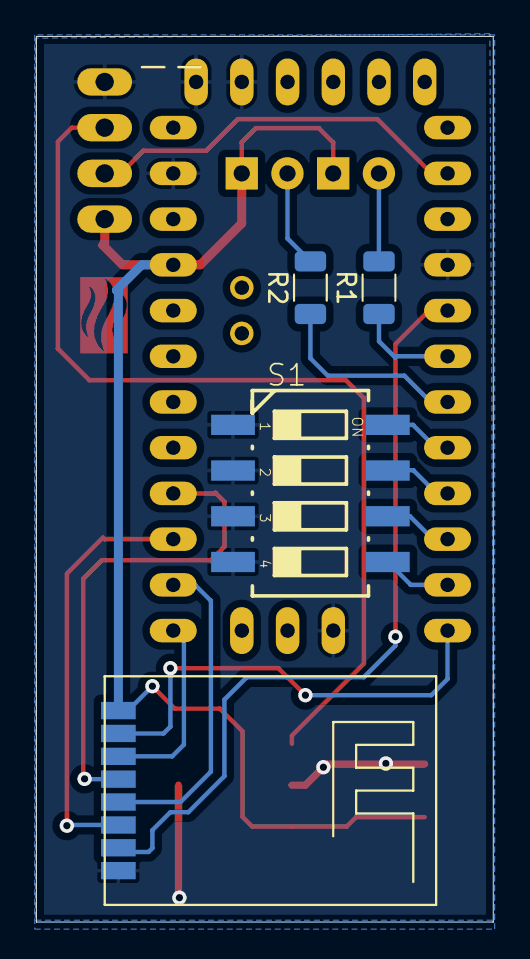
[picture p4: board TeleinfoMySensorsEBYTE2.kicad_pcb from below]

Board: 2 copper layers, 25.4 x 49.2 mm, 12 parts (5 on the bottom side), 18 nets.

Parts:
C1: 100nF; C_1206_3216Metric
C2: 10µF; C_1210_3225Metric
D1, D2: LED; LED_D3.0mm
JP0: PINHD-1X4; 1X04
R1, R2: 1.2k; R_1206_3216Metric
S1: 219-04; CTS-219-04
U1: MCP1703A-3302_SOT223; SOT-223-3_TabPin2
U$1: ABK-PRO-MINI
U$4: FB
U$5: NRFL01SMSEBYTE; 24L01SMDEBYTE

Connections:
GND: C1.2, C2.2, JP0.1, S1.1, S1.2, S1.3, S1.4, U1.2 (GND), U$1.GND, U$1.GND1 (GND2), U$1.GND2 (GND3), U$1.GND3 (GND4), U$1.GND4 (GND1), U$5.GND
unnamed: C1.1, C2.1, D1.1 (K), D2.1 (K), JP0.4, U1.3 (VO), U$1.VCC, U$5.3.3 (VDD)
unnamed: JP0.2, U1.1 (VI)
unnamed: JP0.3, U$1.RX1
unnamed: R1.1, U$1.D3
unnamed: D2.2 (A), R1.2
unnamed: R2.1, U$1.D4
unnamed: D1.2 (A), R2.2
unnamed: S1.5, U$1.D8
unnamed: S1.6, U$1.D7
unnamed: S1.7, U$1.D6
unnamed: S1.8, U$1.D5
unnamed: U$1.D2, U$5.IRQ
unnamed: U$1.D9, U$5.CE
unnamed: U$1.D10, U$5.CSN
unnamed: U$1.D11, U$5.MOSI
unnamed: U$1.D12, U$5.MISO
unnamed: U$1.D13, U$5.SCK

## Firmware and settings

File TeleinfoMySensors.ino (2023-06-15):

/*
 * The MySensors Arduino library handles the wireless radio link and protocol
 * between your home built sensors/actuators and HA controller of choice.
 * The sensors forms a self healing radio network with optional repeaters. Each
 * repeater and gateway builds a routing tables in EEPROM which keeps track of the
 * network topology allowing messages to be routed to nodes.
 *
 * Created by Henrik Ekblad <henrik.ekblad@mysensors.org>
 * Copyright (C) 2013-2018 Sensnology AB
 * Full contributor list: https://github.com/mysensors/MySensors/graphs/contributors
 *
 * Documentation: http://www.mysensors.org
 * Support Forum: http://forum.mysensors.org
 *
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
*/
//--------------------------------------------------------------------
//                 +/          
//                 `hh-        
//        ::        /mm:       
//         hy`      -mmd       
//         omo      +mmm.  -+` 
//         hmy     .dmmm`   od-
//        smmo    .hmmmy    /mh
//      `smmd`   .dmmmd.    ymm
//     `ymmd-   -dmmmm/    omms
//     ymmd.   :mmmmm/    ommd.
//    +mmd.   -mmmmm/    ymmd- 
//    hmm:   `dmmmm/    smmd-  
//    dmh    +mmmm+    :mmd-   
//    omh    hmmms     smm+    
//     sm.   dmmm.     smm`    
//      /+   ymmd      :mm     
//           -mmm       +m:    
//            +mm:       -o    
//             :dy             
//              `+:     
//--------------------------------------------------------------------
//   __|              _/           _ )  |                       
//   _| |  |   ` \    -_)   -_)    _ \  |   -_)  |  |   -_)     
//  _| \_,_| _|_|_| \___| \___|   ___/ _| \___| \_,_| \___|  
//--------------------------------------------------------------------    
// 2019/10/17 - FB V1.0.1
// 2019/12/15 - FB V1.0.2 - optimisation/simplifications et reduction conso mémoire
// 2019/12/17 - FB V1.0.3 - modif led indication envoi MySensors
// 2019/12/22 - FB V1.0.4 - remove warning message
// 2019/12/22 - FB V1.0.5 - optimisation
// 2020/04/25 - FB V1.0.6 - ADCO bug fix
// 2020/04/25 - FB V1.1.0 - Mode standard
// 2020/08/18 - FB V1.1.1 - Correction sur NTARF et LTARF - Merci David MARLINGE
//                        - Ajout EASF01..10, EASD01..04 et ERQ1..4
//                        - Optimisation mémoire
// 2020/08/26 - FB V1.1.2 - Ajout delais sur presentation et send, afin de soulager la gateway
//                        - Envoi données producteur et triphasé si besoin
//                        - Correction sur send EASF et EADS en WH au lieu du VA
//                        - Accents retirés sur les libellés de présentation
// 2020/10/20 - FB V1.1.3 - Ajout options reglages NRF24L01 (puissance, débit, canal)
//                        - Optimisation émission. n'est envoyé que les données de conso changeantes
// 2020/10/26 - FB V1.1.4 - Optimisation bug fix
// 2020/11/12 - FB V1.1.5 - Ajout valeurs min, max sur INSTS..4
//                        - Suppression données à partir de EAS..4, profondeur inutile
// 2021/10/05 - FB V1.1.6 - Ajout prefixes et corrections sur type de compteur
// 2022/06/10 - FB V2.0.0 - Utilisation librairie universelle LibTeleinfo modifiée (pas d'enregistrement, pas assez de RAM sur l'ATmega328 pour avoir une solution stable en TIC full)
//                        - Compatible mode historique et mode standard; détermination automatique au démarrage
// 2022/09/25 - FB V2.0.1 - Correction sur détection TIC standard
// 2023/01/23 - FB V2.0.2 - Correction sur l'envoi des prefixes des chil_id_smax. Merci à Laurent B.
// 2023/02/02 - FB V2.0.3 - Mise à jour librairie LibTeleinfo v1.1.5 avec derniers correctifs https://github.com/hallard/LibTeleinfo/releases
// 2023/02/27 - FB V2.0.4 - Correction sur l'envoi des préfixes CHILD_ID_CCA*
// 2023/03/03 - FB V2.0.5 - Optimisation mémoire
// 2023/04/11 - FB V2.0.6 - Ajout temps maj pour éviter le spam de la gateway et contrôle BASE
// 2023/05/04 - FB V2.0.7 - Amélioration détection mode TIC historique/standard
// 2023/06/03 - FB V2.0.8 - Correction detection TIC historique
// 2023/06/12 - FB V2.0.9 - Ajout compatibilité Arduino pro micro et correction detection TIC historique
// 2023/06/14 - FB V2.1.0 - Modification mise à jour gateway, plus de spam ni de perte d'étiquette. 
//--------------------------------------------------------------------

// Enable debug prints MySensors
//#define MY_DEBUG

//#define DEBUG_TIC

#define CARTE_SWITCH /* A décommenter si utilisation de PCB doté de micro-switchs */

// ----------------------------------------- OPTIONS
#ifdef CARTE_SWITCH
int8_t myNodeId;
#define MY_NODE_ID myNodeId
#else
// #define MY_NODE_ID 123
#endif

/*
 @def MY_RF24_PA_LEVEL
 * @brief Default RF24 PA level. Override in sketch if needed.
 *
 * RF24_PA_MIN = -18dBm
 * RF24_PA_LOW = -12dBm
 * RF24_PA_HIGH = -6dBm    -> par defaut
 * RF24_PA_MAX = 0dBm
 */
#define MY_RF24_PA_LEVEL     RF24_PA_MAX

/*
 * @def MY_RF24_CHANNEL
 * @brief RF channel for the sensor net, 0-125.
 * Frequence: 2400 Mhz - 2525 Mhz Channels: 126
 * http://www.mysensors.org/radio/nRF24L01Plus.pdf
 * 0 => 2400 Mhz (RF24 channel 1)
 * 1 => 2401 Mhz (RF24 channel 2)
 * 76 => 2476 Mhz (RF24 channel 77)   -> par defaut
 * 83 => 2483 Mhz (RF24 channel 84)
 * 124 => 2524 Mhz (RF24 channel 125)
 * 125 => 2525 Mhz (RF24 channel 126)
 * In some countries there might be limitations, in Germany for example only the range 2400,0 - 2483,5 Mhz is allowed
 * http://www.bundesnetzagentur.de/SharedDocs/Downloads/DE/Sachgebiete/Telekommunikation/Unternehmen_Institutionen/Frequenzen/Allgemeinzuteilungen/2013_10_WLAN_2,4GHz_pdf.pdf
 */
//#define MY_RF24_CHANNEL   96       // !! doit être identique sur tous les éléments Mysensors incluant la Gateway

/**
 * @def MY_RF24_DATARATE
 * @brief RF24 datarate (RF24_250KBPS for 250kbs, RF24_1MBPS for 1Mbps or RF24_2MBPS for 2Mbps).
 */
//#define MY_RF24_DATARATE RF24_250KBPS  // Valeur par défaut conservée. !! doit être identique sur tous les éléments Mysensors incluant la Gateway

// ----------------------------------------- FIN OPTIONS

#define VERSION   "v2.1.0"

#define DELAY_PREFIX  50
#define DELAY_PRESENTATION  100

#define MY_SPLASH_SCREEN_DISABLED

#define MY_BAUD_RATE 9600    // mode standard

// Enable and select radio type attached
#define MY_RADIO_RF24

#define MY_DEFAULT_ERR_LED_PIN 3  // Error led pin
#define MY_DEFAULT_RX_LED_PIN  4  // Receive led pin, on board LED
#define MY_DEFAULT_TX_LED_PIN  4  // 

#define SWITCH_1  5
#define SWITCH_2  6
#define SWITCH_3  7
#define SWITCH_4  8

#if defined(__AVR_ATmega32U4__)
#define MY_RF24_CS_PIN 10
#include <avr/wdt.h> 
#else
#warning ---------------------------------------------------------------------------------------------------------------
#warning !! Ce code n'est pas optimisé pour les ATMEGA328p, risque d'instabilité mar manque de mémoire RAM !!
#warning ---------------------------------------------------------------------------------------------------------------
#endif


#include <MySensors.h>
#include "LibTeleinfo.h"

/*
#ifdef __arm__
// should use uinstd.h to define sbrk but Due causes a conflict
extern "C" char* sbrk(int incr);
#else  // __ARM__
extern char *__brkval;
#endif  // __arm__
*/

unsigned long startTime; // Date démarrage 
_Mode_e mode_tic;
boolean flag_first = true;
boolean flag_full_tic = true;
boolean flag_tic = true;
unsigned long memo_BASE = 0;
const unsigned long SEND_FREQUENCY_FULL = 300000; // 5mn, Minimum time between send (in milliseconds). 
unsigned long lastTime_full = 0;

TInfo tinfo;

#define char_AMPERE "A"
#define char_VOLT "V"
#define char_WATT "W"
#define char_WATT_HEURE "Wh"
#define char_VA "VA"
#define char_KVA "kVA"
#define char_VAR_HEURE "VArh"
#define char_MIN "min"

// Mode Historique ------------
const char char_ADCO[] PROGMEM = "ADCO";
const char char_OPTARIF[] PROGMEM = "OPTARIF";
const char char_ISOUSC[] PROGMEM = "ISOUSC";
const char char_BASE[] PROGMEM = "BASE";
const char char_HCHC[] PROGMEM = "HCHC";
const char char_HCHP[] PROGMEM = "HCHP";
const char char_EJPHN[] PROGMEM = "EJPHN";
const char char_EJPHPM[] PROGMEM = "EJPHPM";
const char char_BBRHCJB[] PROGMEM = "BBRHCJB";
const char char_BBRHPJB[] PROGMEM = "BBRHPJB";
const char char_BBRHCJW[] PROGMEM = "BBRHCJW";
const char char_BBRHPJW[] PROGMEM = "BBRHPJW";
const char char_BBRHCJR[] PROGMEM = "BBRHCJR";
const char char_BBRHPJR[] PROGMEM = "BBRHPJR";
const char char_PEJP[] PROGMEM = "PEJP";
const char char_PTEC[] PROGMEM = "PTEC";
const char char_DEMAIN[] PROGMEM = "DEMAIN";
const char char_IINST[] PROGMEM = "IINST";
const char char_ADPS[] PROGMEM = "ADPS";
const char char_IMAX[] PROGMEM = "IMAX";
const char char_PAPP[] PROGMEM = "PAPP";
const char char_HHPHC[] PROGMEM = "HHPHC";
const char char_MOTDETAT[] PROGMEM = "MOTDETAT";
const char char_IINST1[] PROGMEM = "IINST1";
const char char_IINST2[] PROGMEM = "IINST2";
const char char_IINST3[] PROGMEM = "IINST3";
const char char_IMAX1[] PROGMEM = "IMAX1";
const char char_IMAX2[] PROGMEM = "IMAX2";
const char char_IMAX3[] PROGMEM = "IMAX3";
const char char_PMAX[] PROGMEM = "PMAX";
const char char_PPOT[] PROGMEM = "PPOT";
const char char_ADIR1[] PROGMEM = "ADIR1";
const char char_ADIR2[] PROGMEM = "ADIR2";
const char char_ADIR3[] PROGMEM = "ADIR3";

#define CHILD_ID_ADCO 1
#define CHILD_ID_OPTARIF 2
#define CHILD_ID_ISOUSC 3
#define CHILD_ID_BASE 4
#define CHILD_ID_HCHC 5
#define CHILD_ID_HCHP 6
#define CHILD_ID_EJPHN 7
#define CHILD_ID_EJPHPM 8
#define CHILD_ID_BBRHCJB 9
#define CHILD_ID_BBRHPJB 10
#define CHILD_ID_BBRHCJW 11
#define CHILD_ID_BBRHPJW 12
#define CHILD_ID_BBRHCJR 13
#define CHILD_ID_BBRHPJR 14
#define CHILD_ID_PEJP 15
#define CHILD_ID_PTEC 16
#define CHILD_ID_DEMAIN 17
#define CHILD_ID_IINST 18
#define CHILD_ID_ADPS 19
#define CHILD_ID_IMAX 20
#define CHILD_ID_PAPP 21
#define CHILD_ID_HHPHC 22
#define CHILD_ID_MOTDETAT 23
#define CHILD_ID_IINST1 24
#define CHILD_ID_IINST2 25
#define CHILD_ID_IINST3 26
#define CHILD_ID_IMAX1 27
#define CHILD_ID_IMAX2 28
#define CHILD_ID_IMAX3 29
#define CHILD_ID_PMAX 30
#define CHILD_ID_PPOT 31
#define CHILD_ID_ADIR1 32
#define CHILD_ID_ADIR2 33
#define CHILD_ID_ADIR3 34


// Mode Standard --------------
const char char_ADSC[] PROGMEM = "ADSC";
const char char_VTIC[] PROGMEM = "VTIC";
const char char_DATE[] PROGMEM = "DATE";
const char char_NGTF[] PROGMEM = "NGTF";
const char char_LTARF[] PROGMEM = "LTARF";
const char char_EAST[] PROGMEM = "EAST";
const char char_EASF01[] PROGMEM = "EASF01";
const char char_EASF02[] PROGMEM = "EASF02";
const char char_EASF03[] PROGMEM = "EASF03";
const char char_EASF04[] PROGMEM = "EASF04";
//const char char_EASF05[] PROGMEM = "EASF05";
//const char char_EASF06[] PROGMEM = "EASF06";
//const char char_EASF07[] PROGMEM = "EASF07";
//const char char_EASF08[] PROGMEM = "EASF08";
//const char char_EASF09[] PROGMEM = "EASF09";
//const char char_EASF10[] PROGMEM = "EASF10";
const char char_EASD01[] PROGMEM = "EASD01";
const char char_EASD02[] PROGMEM = "EASD02";
const char char_EASD03[] PROGMEM = "EASD03";
const char char_EASD04[] PROGMEM = "EASD04";
const char char_EAIT[] PROGMEM = "EAIT";
const char char_ERQ1[] PROGMEM = "ERQ1";
const char char_ERQ2[] PROGMEM = "ERQ2";
const char char_ERQ3[] PROGMEM = "ERQ3";
const char char_ERQ4[] PROGMEM = "ERQ4";
const char char_IRMS1[] PROGMEM = "IRMS1";
const char char_IRMS2[] PROGMEM = "IRMS2";
const char char_IRMS3[] PROGMEM = "IRMS3";
const char char_URMS1[] PROGMEM = "URMS1";
const char char_URMS2[] PROGMEM = "URMS2";
const char char_URMS3[] PROGMEM = "URMS3";
const char char_PREF[] PROGMEM = "PREF";
const char char_PCOUP[] PROGMEM = "PCOUP";
const char char_SINSTS[] PROGMEM = "SINSTS";
const char char_SINSTS1[] PROGMEM = "SINSTS1";
const char char_SINSTS2[] PROGMEM = "SINSTS2";
const char char_SINSTS3[] PROGMEM = "SINSTS3";
const char char_SMAXSN[] PROGMEM = "SMAXSN";
const char char_SMAXSN1[] PROGMEM = "SMAXSN1";
const char char_SMAXSN2[] PROGMEM = "SMAXSN2";
const char char_SMAXSN3[] PROGMEM = "SMAXSN3";
const char char_SMAXSN_1[] PROGMEM = "SMAXSN-1";
const char char_SMAXSN1_1[] PROGMEM = "SMAXSN1-1";
const char char_SMAXSN2_1[] PROGMEM = "SMAXSN2-1";
const char char_SMAXSN3_1[] PROGMEM = "SMAXSN3-1";
const char char_SINSTI[] PROGMEM = "SINSTI";
const char char_SMAXIN[] PROGMEM = "SMAXIN";
const char char_SMAXIN_1[] PROGMEM = "SMAXIN-1";
const char char_CCASN[] PROGMEM = "CCASN";
const char char_CCASN_1[] PROGMEM = "CCASN-1";
const char char_CCAIN[] PROGMEM = "CCAIN";
const char char_CCAIN_1[] PROGMEM = "CCAIN-1";
const char char_UMOY1[] PROGMEM = "UMOY1";
const char char_UMOY2[] PROGMEM = "UMOY2";
const char char_UMOY3[] PROGMEM = "UMOY3";
const char char_STGE[] PROGMEM = "STGE";
const char char_DPM1[] PROGMEM = "DPM1";
const char char_DPM2[] PROGMEM = "DPM2";
const char char_DPM3[] PROGMEM = "DPM3";
const char char_FPM1[] PROGMEM = "FPM1";
const char char_FPM2[] PROGMEM = "FPM2";
const char char_FPM3[] PROGMEM = "FPM3";
const char char_MSG1[] PROGMEM = "MSG1";
const char char_MSG2[] PROGMEM = "MSG2";
const char char_PRM[] PROGMEM = "PRM";
const char char_RELAIS[] PROGMEM = "RELAIS";
const char char_NTARF[] PROGMEM = "NTARF";
const char char_NJOURF[] PROGMEM = "NJOURF";
const char char_NJOURF_1[] PROGMEM = "NJOURF+1";
const char char_PJOURF_1[] PROGMEM = "PJOURF+1";
const char char_PPOINTE[] PROGMEM = "PPOINTE";

#define CHILD_ID_ADSC     1
#define CHILD_ID_VTIC     2
#define CHILD_ID_DATE     3
#define CHILD_ID_NGTF     4
#define CHILD_ID_LTARF     5
#define CHILD_ID_EAST     6
#define CHILD_ID_EASF01     7
#define CHILD_ID_EASF02     8
#define CHILD_ID_EASF03     9
#define CHILD_ID_EASF04     10
//#define CHILD_ID_EASF05     11
//#define CHILD_ID_EASF06     12
//#define CHILD_ID_EASF07     13
//#define CHILD_ID_EASF08     14
//#define CHILD_ID_EASF09     15
//#define CHILD_ID_EASF10     16
#define CHILD_ID_EASD01     17
#define CHILD_ID_EASD02     18
#define CHILD_ID_EASD03     19
#define CHILD_ID_EASD04     20
#define CHILD_ID_EAIT     21
#define CHILD_ID_ERQ1     22
#define CHILD_ID_ERQ2     23
#define CHILD_ID_ERQ3     24
#define CHILD_ID_ERQ4     25
#define CHILD_ID_IRMS1     26
#define CHILD_ID_IRMS2     27
#define CHILD_ID_IRMS3     28
#define CHILD_ID_URMS1     29
#define CHILD_ID_URMS2     30
#define CHILD_ID_URMS3     31
#define CHILD_ID_PREF     32
#define CHILD_ID_PCOUP     33
#define CHILD_ID_SINSTS     34
#define CHILD_ID_SINSTS1     35
#define CHILD_ID_SINSTS2     36
#define CHILD_ID_SINSTS3     37
#define CHILD_ID_SMAXSN     38
#define CHILD_ID_SMAXSN1     39
#define CHILD_ID_SMAXSN2     40
#define CHILD_ID_SMAXSN3     41
#define CHILD_ID_SMAXSN_1     42
#define CHILD_ID_SMAXSN1_1     43
#define CHILD_ID_SMAXSN2_1     44
#define CHILD_ID_SMAXSN3_1     45
#define CHILD_ID_SINSTI     46
#define CHILD_ID_SMAXIN     47
#define CHILD_ID_SMAXIN_1     48
#define CHILD_ID_CCASN     49
#define CHILD_ID_CCASN_1     50
#define CHILD_ID_CCAIN     51
#define CHILD_ID_CCAIN_1     52
#define CHILD_ID_UMOY1     53
#define CHILD_ID_UMOY2     54
#define CHILD_ID_UMOY3     55
#define CHILD_ID_STGE     56
#define CHILD_ID_DPM1     57
#define CHILD_ID_DPM2     58
#define CHILD_ID_DPM3     59
#define CHILD_ID_FPM1     60
#define CHILD_ID_FPM2     61
#define CHILD_ID_FPM3     62
#define CHILD_ID_MSG1     63
#define CHILD_ID_MSG2     64
#define CHILD_ID_PRM     65
#define CHILD_ID_RELAIS     66
#define CHILD_ID_NTARF     67
#define CHILD_ID_NJOURF     68
#define CHILD_ID_NJOURF_1     69
#define CHILD_ID_PJOURF_1     70
#define CHILD_ID_PPOINTE     71
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
void loop()
{
  uint32_t currentTime = millis();
  
  if (flag_first) {
	// Send prefix au démarrage
    if (mode_tic == TINFO_MODE_HISTORIQUE) {
      send(msgPrefix.setSensor(CHILD_ID_ISOUSC).set(char_AMPERE));
      send(msgPrefix.setSensor(CHILD_ID_BASE).set(char_WATT_HEURE));
      send(msgPrefix.setSensor(CHILD_ID_HCHC).set(char_WATT_HEURE));
      send(msgPrefix.setSensor(CHILD_ID_HCHP).set(char_WATT_HEURE));
      send(msgPrefix.setSensor(CHILD_ID_EJPHN).set(char_WATT_HEURE));
      wait(DELAY_PREFIX);
      send(msgPrefix.setSensor(CHILD_ID_EJPHPM).set(char_WATT_HEURE));
      send(msgPrefix.setSensor(CHILD_ID_BBRHCJB).set(char_WATT_HEURE));
      send(msgPrefix.setSensor(CHILD_ID_BBRHPJB).set(char_WATT_HEURE));
      send(msgPrefix.setSensor(CHILD_ID_BBRHCJW).set(char_WATT_HEURE));
      send(msgPrefix.setSensor(CHILD_ID_BBRHPJW).set(char_WATT_HEURE));
      wait(DELAY_PREFIX);
      send(msgPrefix.setSensor(CHILD_ID_BBRHCJR).set(char_WATT_HEURE));
      send(msgPrefix.setSensor(CHILD_ID_BBRHPJR).set(char_WATT_HEURE));
      send(msgPrefix.setSensor(CHILD_ID_PEJP).set(char_MIN));
      send(msgPrefix.setSensor(CHILD_ID_IINST).set(char_AMPERE));
      send(msgPrefix.setSensor(CHILD_ID_ADPS).set(char_AMPERE));
      wait(DELAY_PREFIX);
      send(msgPrefix.setSensor(CHILD_ID_IMAX).set(char_AMPERE));
      send(msgPrefix.setSensor(CHILD_ID_PAPP).set(char_VA));
      send(msgPrefix.setSensor(CHILD_ID_IINST1).set(char_AMPERE));
      send(msgPrefix.setSensor(CHILD_ID_IINST2).set(char_AMPERE));
      send(msgPrefix.setSensor(CHILD_ID_IINST3).set(char_AMPERE));
      wait(DELAY_PREFIX);
      send(msgPrefix.setSensor(CHILD_ID_IMAX1).set(char_AMPERE));
      send(msgPrefix.setSensor(CHILD_ID_IMAX2).set(char_AMPERE));
      send(msgPrefix.setSensor(CHILD_ID_IMAX3).set(char_AMPERE));
      send(msgPrefix.setSensor(CHILD_ID_PMAX).set(char_WATT));
      send(msgPrefix.setSensor(CHILD_ID_ADIR1).set(char_AMPERE));
      wait(DELAY_PREFIX);
      send(msgPrefix.setSensor(CHILD_ID_ADIR2).set(char_AMPERE));
      send(msgPrefix.setSensor(CHILD_ID_ADIR3).set(char_AMPERE));
    }
    else {
      send(msgPrefix.setSensor(CHILD_ID_EAST).set(char_WATT_HEURE));
      send(msgPrefix.setSensor(CHILD_ID_EASF01).set(char_WATT_HEURE));
      send(msgPrefix.setSensor(CHILD_ID_EASF02).set(char_WATT_HEURE));
      send(msgPrefix.setSensor(CHILD_ID_EASF03).set(char_WATT_HEURE));
      send(msgPrefix.setSensor(CHILD_ID_EASF04).set(char_WATT_HEURE));
      wait(DELAY_PREFIX);
 //     send(msgPrefix.setSensor(CHILD_ID_EASF05).set(char_WATT_HEURE));
 //     send(msgPrefix.setSensor(CHILD_ID_EASF06).set(char_WATT_HEURE));
 //     send(msgPrefix.setSensor(CHILD_ID_EASF07).set(char_WATT_HEURE));
 //     send(msgPrefix.setSensor(CHILD_ID_EASF08).set(char_WATT_HEURE));
 //     send(msgPrefix.setSensor(CHILD_ID_EASF09).set(char_WATT_HEURE));
 //     wait(DELAY_PREFIX);
 //     send(msgPrefix.setSensor(CHILD_ID_EASF10).set(char_WATT_HEURE));
      send(msgPrefix.setSensor(CHILD_ID_EASD01).set(char_WATT_HEURE));
      send(msgPrefix.setSensor(CHILD_ID_EASD02).set(char_WATT_HEURE));
      send(msgPrefix.setSensor(CHILD_ID_EASD03).set(char_WATT_HEURE));
      send(msgPrefix.setSensor(CHILD_ID_EASD04).set(char_WATT_HEURE));
      wait(DELAY_PREFIX);
      send(msgPrefix.setSensor(CHILD_ID_EAIT).set(char_WATT_HEURE));
      send(msgPrefix.setSensor(CHILD_ID_ERQ1).set(char_VAR_HEURE));
      send(msgPrefix.setSensor(CHILD_ID_ERQ2).set(char_VAR_HEURE));
      send(msgPrefix.setSensor(CHILD_ID_ERQ3).set(char_VAR_HEURE));
      send(msgPrefix.setSensor(CHILD_ID_ERQ4).set(char_VAR_HEURE));
      wait(DELAY_PREFIX);
      send(msgPrefix.setSensor(CHILD_ID_IRMS1).set(char_AMPERE));
      send(msgPrefix.setSensor(CHILD_ID_IRMS2).set(char_AMPERE));
      send(msgPrefix.setSensor(CHILD_ID_IRMS3).set(char_AMPERE));
      send(msgPrefix.setSensor(CHILD_ID_URMS1).set(char_VOLT));
      send(msgPrefix.setSensor(CHILD_ID_URMS2).set(char_VOLT));
      wait(DELAY_PREFIX);
      send(msgPrefix.setSensor(CHILD_ID_URMS3).set(char_VOLT));
      send(msgPrefix.setSensor(CHILD_ID_PREF).set(char_KVA));
      send(msgPrefix.setSensor(CHILD_ID_PCOUP).set(char_KVA));
      send(msgPrefix.setSensor(CHILD_ID_SINSTS).set(char_VA));
      send(msgPrefix.setSensor(CHILD_ID_SINSTS1).set(char_VA));
      wait(DELAY_PREFIX);
      send(msgPrefix.setSensor(CHILD_ID_SINSTS2).set(char_VA));
      send(msgPrefix.setSensor(CHILD_ID_SINSTS3).set(char_VA));
      send(msgPrefix.setSensor(CHILD_ID_SMAXSN).set(char_VA));
      send(msgPrefix.setSensor(CHILD_ID_SMAXSN1).set(char_VA));
      send(msgPrefix.setSensor(CHILD_ID_SMAXSN2).set(char_VA));
      wait(DELAY_PREFIX);
      send(msgPrefix.setSensor(CHILD_ID_SMAXSN3).set(char_VA));
      send(msgPrefix.setSensor(CHILD_ID_SMAXSN_1).set(char_VA));
      send(msgPrefix.setSensor(CHILD_ID_SMAXSN1_1).set(char_VA));
      send(msgPrefix.setSensor(CHILD_ID_SMAXSN2_1).set(char_VA));
      send(msgPrefix.setSensor(CHILD_ID_SMAXSN3_1).set(char_VA));
      wait(DELAY_PREFIX);
      send(msgPrefix.setSensor(CHILD_ID_SINSTI).set(char_VA));
      send(msgPrefix.setSensor(CHILD_ID_SMAXIN).set(char_VA));
      send(msgPrefix.setSensor(CHILD_ID_SMAXIN_1).set(char_VA));
      send(msgPrefix.setSensor(CHILD_ID_CCASN).set(char_WATT));
      send(msgPrefix.setSensor(CHILD_ID_CCASN_1).set(char_WATT));
      wait(DELAY_PREFIX);
      send(msgPrefix.setSensor(CHILD_ID_CCAIN).set(char_WATT));
      send(msgPrefix.setSensor(CHILD_ID_CCAIN_1).set(char_WATT));
      send(msgPrefix.setSensor(CHILD_ID_UMOY1).set(char_VOLT));
      send(msgPrefix.setSensor(CHILD_ID_UMOY2).set(char_VOLT));
      send(msgPrefix.setSensor(CHILD_ID_UMOY3).set(char_VOLT));
      wait(DELAY_PREFIX);
    }

    send(msgTEXT.setSensor(CHILD_ID_START).set(startTime));
    #if defined(__AVR_ATmega32U4__)
    char val_mcusr[10];
    sprintf(val_mcusr, "%02X", MCUSR);
    send(msgTEXT.setSensor(CHILD_ID_WD).set(val_mcusr));
    #endif
	
    tinfo.attachData(DataCallback);
      
    flag_first= false;
  } 
  
  #if defined(__AVR_ATmega32U4__)
  if (Serial1.available()) tinfo.process(Serial1.read());
  wdt_reset();
  #else
  if (Serial.available()) tinfo.process(Serial.read());
  #endif

  // envoyer l'ensemble des données tous les SEND_FREQUENCY_FULL ms
  if (currentTime - lastTime_full > SEND_FREQUENCY_FULL) {
    Serial.println(F("SEND_FULL"));
    flag_full_tic = true;
    lastTime_full = currentTime;
  }

}

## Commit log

2020-04-23 Add files via upload
    ADCO bug fix
    [TeleinfoMySensors.ino]
2020-04-25 ADCO bug fix
    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
    [TeleinfoMySensors.ino]
2020-08-26 V1.1.2
    - Ajout delais sur presentation et send, afin de soulager la gateway
    - Envoi données producteur et triphasé si besoin
    - Correction sur send EASF et EADS en WH au lieu du VA
    [TeleinfoMySensors.ino]
2020-09-01 1.1.2
    - Accents retirés sur les libellés de présentation
    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
    [TeleinfoMySensors.ino]
2020-10-26 1.1.4
    Optimisation bug fix
    [TeleinfoMySensors.ino]
2021-05-12 1.1.5
    Correction erreur de compil et optimisation
    [TeleinfoMySensors.ino]
2021-10-05 Ajout prefixes et corrections sur type de compteur
    Ajout prefixes et corrections sur type de compteur
    [TeleinfoMySensors.ino]
2022-06-24 V2.0.0
    Utilisation librairie universelle LibTeleinfo modifiée (pas d'enregistrement, pas assez de RAM sur l'ATmega328 pour avoir une solution stable en TIC full)
    Compatible mode historique et mode standard; détermination automatique au démarrage
    Attention tous les commandes MySensors ont été revues (n° différent pour certaines)
2022-09-27 v2.0.1
    Correction sur détection TIC standard
    [TeleinfoMySensors.ino]
2022-12-20 2.0.3
    Kicad PCB with DIP switch
    [AlimTeleinfoMySensors.kicad_pcb, AlimTeleinfoMySensors.kicad_sch, TeleinfoMySensorsEBYTE2.kicad_pcb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]
2023-01-27 v2.0.2
    Correction sur l'envoi des prefixes des chil_id_smax. Merci à Laurent B.
    [TeleinfoMySensors.ino]
2023-02-02 V2.0.3
    Mise à jour librairie LibTeleinfo v1.1.5 avec derniers correctifs https://github.com/hallard/LibTeleinfo/releases
    [TeleinfoMySensors.ino]
2023-02-27 v2.0.4
    Correction sur l'envoi des préfixes CHILD_ID_CCA*
    [TeleinfoMySensors.ino]
2023-04-17 v2.0.6
    Ajout temps maj pour éviter le spam de la gateway et contrôle étiquette BASE
2023-06-03 V2.0.8
    Correction detection TIC historique
    [TeleinfoMySensors.ino]
2023-06-14 v2.0.9
    Ajout compatibilité Arduino pro micro et correction detection TIC historique
    [TeleinfoMySensors.ino]
2023-06-15 v2.1.0
    Modification mise à jour gateway, plus de spam ni de perte d'étiquette.
    Code optimisé pour l'arduino pro micro ATMEGA32u4

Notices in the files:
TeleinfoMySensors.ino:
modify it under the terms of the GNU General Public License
